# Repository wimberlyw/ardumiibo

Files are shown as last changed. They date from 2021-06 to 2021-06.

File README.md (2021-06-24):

# Arduboy Pro Rumble - With Ardumiibo Scanner
### The Arduboy Pro Rumble itself is a homemade Leonardo backpack that has a vibration motor attached to Speaker Pin 2. Game makers can use the Arduboy2 Tones commands to add rumble to their game. The system also features broken out Serial connection to connect the the Ardumiibo Scanner and future peripherals.

### The Ardumiibo scanner is a PN532 NFC Scanner with a Neopixel ring that can scan collectible items from the real world into your game. 

## An Arduboy based nod to Tiger Electronics handhelds, Rumble Features, and [Amiibos](https://www.nintendo.com/amiibo/)

### [Watch The Youtube Playlist Before You Begin](https://youtube.com/playlist?list=PLI37KAai0mUhJ3Yi7gZaNxqZhPj6SuK46)

Cover
# TOC

1. [Bill of Materials](https://github.com/wimberlyw/ardumiibo#materials-needed)
2. [Assembly](https://github.com/wimberlyw/ardumiibo#assembly)
    - Arduboy Pro Rumble Game Console
    - Powerboost
    - Boost Cables
    - Scanner
3. [Software](https://github.com/wimberlyw/ardumiibo#software)
4. [Examples](https://github.com/wimberlyw/ardumiibo#load-your-scanner-pro-micro-up-with-the-nfc-reader)  

## Materials Needed:

### Arduboy Pro Rumble:
- Arduino Leonardo
- 10mm x 2.5mm Disc Shape Vibration Motor for Cell Phone - 3v
  - Mine was from uxcel but these look just as good. (https://www.amazon.com/tatoko-12000RPM-Wired-Phone-Vibration/dp/B07L5V5GYG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)
 - 2n2222 NPN transistor
 - 3x 110 ohm resistors
 - 10uF 50V capacitor
 - Diode
 - 7x tactile momentary push buttons
 - RGB LED
 - piezo buzzer
 - On off switch
 - 2.42" i2c SSD1309 OLED
 - USB data cable (for booster cable)
 - [3d printer files](https://github.com/wimberlyw/ardumiibo/tree/main/3d%20parts)
 - [Adafruit Powerboost 500](https://www.adafruit.com/product/1944)
    - [Booster cable for Powerboost](https://learn.adafruit.com/booster-cable)
- [3.7V 1200mAh Lipo Battery](https://www.amazon.com/gp/product/B00J2QET64/ref=ppx_yo_dt_b_search_asin_title?ie=UTF8&psc=1)

### Ardumiibo Scanner
-  [3d printer files](https://github.com/wimberlyw/ardumiibo/tree/main/3d%20parts)
-  [24LED Neopixel ring] (https://www.amazon.com/gp/product/B0774JNSCF/ref=ppx_yo_dt_b_search_asin_title?ie=UTF8&psc=1)
-  [PN532 NFC Reader](https://www.amazon.com/gp/product/B01I1J17LC/ref=ppx_yo_dt_b_search_asin_title?ie=UTF8&psc=1)
- USB data cable (for booster cable)
- [Adafruit Powerboost 500](https://www.adafruit.com/product/1944)
- On off switch
- [Booster cable for Powerboost](https://learn.adafruit.com/booster-cable)
- [3.7v 500 mAh Lipo battery](https://www.amazon.com/gp/product/B00L0W61VO/ref=ppx_yo_dt_b_search_asin_title?ie=UTF8&psc=1)
- Leonardo Pro Micro
- Perfboard to mount up everything nice 
- NFC stickers for ardumiibos. (https://www.amazon.com/THONSEN-NTAG215-Stickers-Perfectly-NFC-Enabled/dp/B07MKWHYQK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)
- 

## Assembly
  	- Good luck.
  - Add hot glue as wire stress relief as you go. 
  
- Start printing the 3d printer files listed in the 3d parts section of this Github or listed in the BOM above. 

### Arduboy Pro Rumble
- You can either contact me for a pcb and I can order some more, you can make your own using the schematics from the giuthub, or you can breadboard this out. Up to you. 

### Front side PCB
1. Solder the Male header pins into the middle of the PCB so that it's like a backpack for the Leonardo. The Male pins on the PCB face **DOWN** towards the Leonardo female pins. 
backpack

2. Solder in your two resistors top right, and the 7x tactile buttons onto the top of the board. 
3. Solder in your Screen. All the pins should line up on the left hand side. If you're breadboarding this, refer to the schematics for how to hook up the display.
  -  The only items facing the front of the PCB are the buttons and those two resistors. And the Screen

### Back Side PCB

1. Install female header pins where the broken out ICSP header is. 
2. Directly beneath the female header pins, install the third resistor. 
3. Solder in the transistor with the flat part facing up, curved part towards the bottom. 
4. Solder in the diode with the white stripe facing the way it is on the board. Once again refer to the schematic for help, or the pictures on the pcb. 
5. Install the capacitor with negative stripe facing the right. 

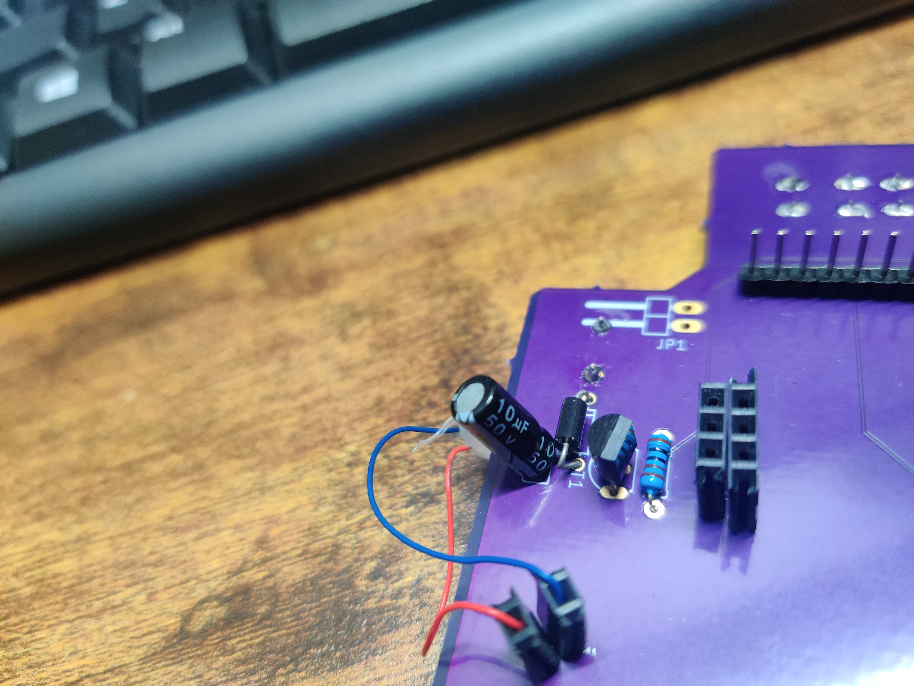
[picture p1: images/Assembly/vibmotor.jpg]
rumble


- I would install the Speaker, vibraating motor, and RGBLED on the back of the PCB. 

6. The vibrating motor goes on the two holes to the right of the capacitor circuit. Install the vibrating motor with ground wire on the left. (If PCB back is facing you.)

7. The speaker is labeled for the front, but I find it works better on the bottom of the board. the speaker wire holes are directly left of the diode.(If PCB back is facing you.) Solder in the piezo speaker with the positive wire on the left.

8. The serial cable wires are also labeled for the top, but I like them better on the bottom. You should be able to see the traces on the PCB. If the back of the OCB is facing you RX is the left hole of the gold pads. TX is the right. (the front of the board has them labeled as JP1.)

9. You're also going to need to tack a ground wire onto one of the nubs of a ground wire, as you need this for serial and I forgot. 
- This illustrates the ground wire, but the other wires are on top, which I mentioned not to do. 

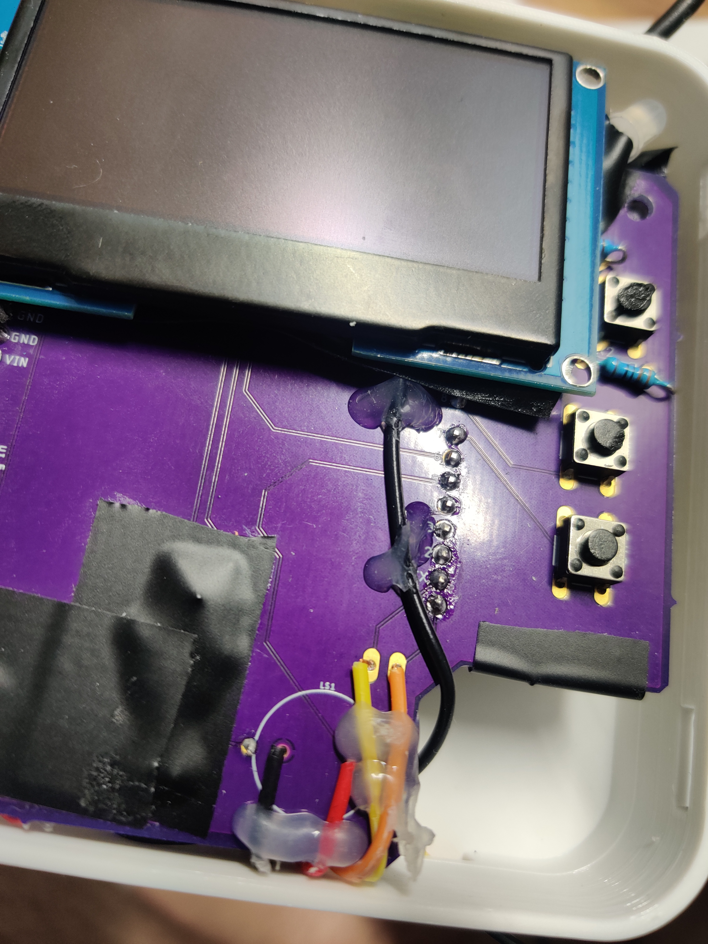
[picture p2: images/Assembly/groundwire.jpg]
Ground


##
## At this point you should be able to backpack the PCB onto the Leonardo
##
### Now we need to make the booster cables so we can power up the arduino.
  - You should probably hook everything up to your data cable at this point and run the included "Rumble Demo" to make sure everything's working right. We're about to cut up that data cable so, test it now, anyway. 
  -
  
 ## Powerboost and Booster Cables
 
 1. Follow the directions from Adafruit to hook up a switch to your Powerboost. You're going to want to mount the switch with wires instead of directly to the board so we can remote mount it. 
  - https://learn.adafruit.com/adafruit-powerboost-500-plus-charger/on-slash-off-switch

  - onOff

### You may as well wire up both powerboosts, and make two boost cables. We need the boost cables to be able to pass data through . 

2. https://learn.adafruit.com/booster-cable

## It's Time To
## Shove thaat thang in the case.
### Let me just preface this with I didn't know the powerboost would take up so much room. They look so small. 
### And I'm new to Fusion360. 
#### Sowwy. 
#### Do your best to put everything in the case and rout the USB out the top holes, and the Serial cable out the bottom. It's pretty self explanatory so here are some pictures of how I did it. Feel free to design your own case at this point. 

#### Glue down the Piezo and the vibrating motor to the back inside of the, where the empty resources are. You probably want to add a few dabs of glue to the front part of the case to keep your d pad in place, too. 

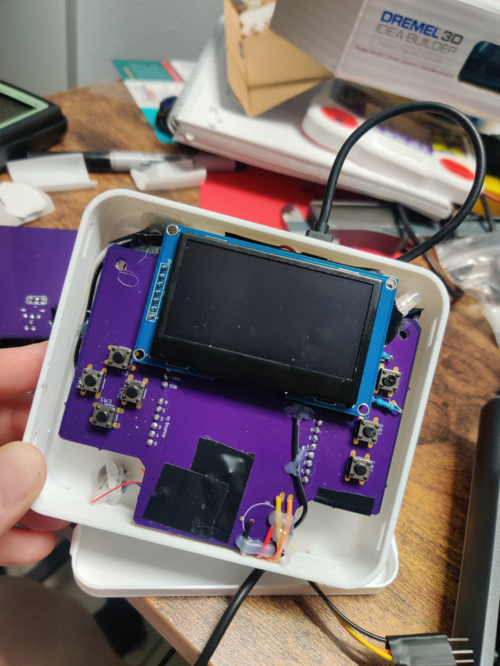
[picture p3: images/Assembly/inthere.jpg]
inthere


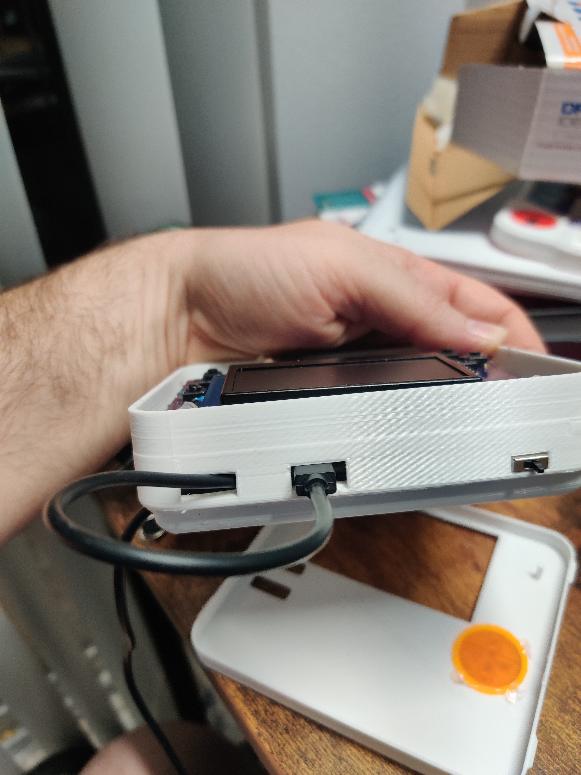
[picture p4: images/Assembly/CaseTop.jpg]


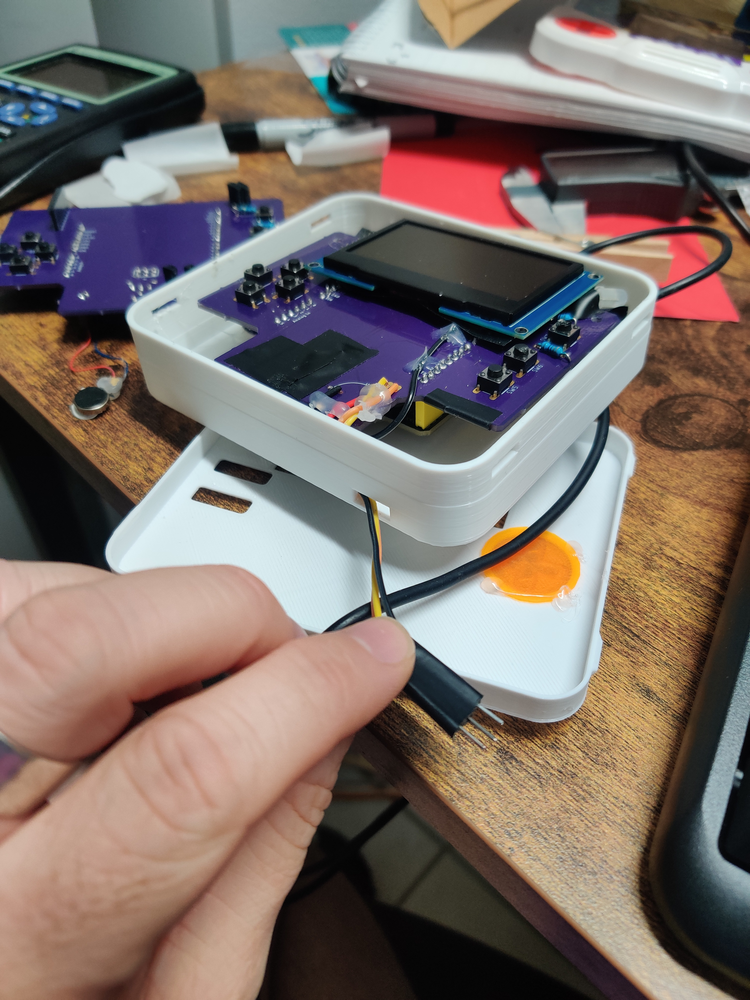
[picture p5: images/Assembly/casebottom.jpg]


## Should look like this 
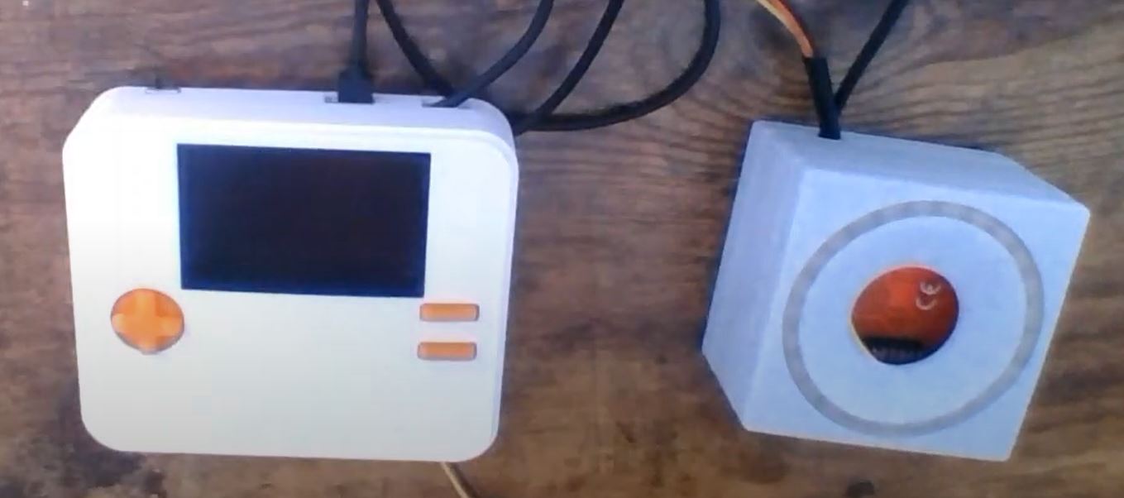
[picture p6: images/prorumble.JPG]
done


## Ardumiibo Scanner Assembly

1. On the **PN532 NFC RFID module** Solder on the 4 90 degree pins that came with your module so that they are sticking out the side that reads "TXD RXD"
2. Carefully switch the module to IIC/ I2c mode by flipping the jumper. 
  - More info can be found here: https://www.electroschematics.com/nfc-rfid-module-pn532/
  - And here: http://wiki.sunfounder.cc/index.php?title=PN532_NFC_RFID_Module
3. The Arduino Pro Micro will sit in the bottom of the Scanner case, along with the Powerboost hooked up to it's booster cable
 - https://learn.adafruit.com/booster-cable
4. The middle bdoy is where the PN532 will sit, and you will pass wires through the holes to the bottom of the case.  (If you've printed the case this will be very evident.)
5. The top faceplate is in 3 parts, and the NEOPIXEL ring is glued into the back of the light diffuser ring part. 
6. Run the wires from the top section of the box where the LEDs are, THrough the body, and into the base so you can solder them into the Pro Micro as follows. 

Pro Micro | Module
------------ | -------------
VCC | VCC PN532
VCC | 5v LED Ring 
GND | GND PN532
GND | GND LED Ring
Pin 2 | PN532/ SDA
PIN 3 | PN532/ SCL
PIN 4 | LED Ring Data In

RFIDclose

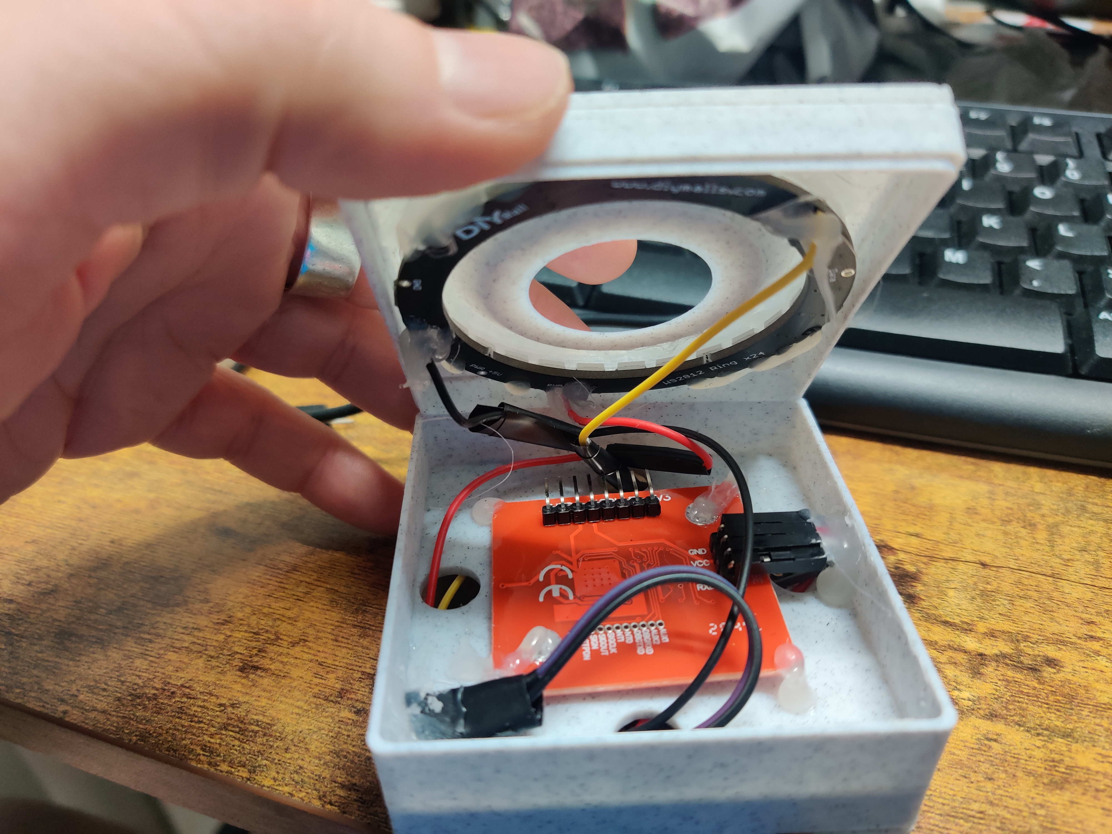
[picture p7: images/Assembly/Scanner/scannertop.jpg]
ScanTop


### Unfortunately I can't show you the wires in the pro micro because fitting everything in the box is a hard task. Once it's in there, it's in. 
 - Use plenty of hot glue for attaching and wire stress relief. 

## Software

- I use the Arduino IDE so I can't speak to the Arduboy game loaders. 
- Use Mr Blinky's homemade Package for running the 1309. Select Homemade Arduboy, Leonardo, and SSD1309. Standard Arduino Core.
  - https://github.com/MrBlinky/Arduboy-homemade-package
  - Blinky's software worked for me out of the box, but I remember way back having to change some addresses or running the patcher for uploading games. You can find out all about that on the Arduboy forums and in Mr. Blinky's docs. 

- Install the PN532 Arduino Library
  - https://github.com/Seeed-Studio/PN532/tree/arduino/PN532

- Install the Adafruit Neopixel Library 
  - https://learn.adafruit.com/adafruit-neopixel-uberguide/arduino-library-installation

### Load your scanner Pro Micro up with the NFC Reader 

- (https://github.com/wimberlyw/ardumiibo/tree/main/Scanner%20Programs)
    -  This is basically boilperplate from the PN532 libraries, and the Adafruit Neopixel library.

### Load your Arduboy Pro Rumble up with the example ScanDemo

-https://github.com/wimberlyw/ardumiibo/tree/main/Examples
 
 ### Check out the video tutorial on how to make an Ardumiibo. 
 
 - https://youtu.be/rNLjulla09I
  - Use the word "keys" for the key example
  - Use "pots" for the potion example. 
  - Try Everything out!
 
 ## Try the "Turbo Waddle" Demo!
 
 - https://youtu.be/9yPsy_AzS58
 - https://github.com/wimberlyw/ardumiibo/tree/main/Game/TurboWaddle

## Make your own game with Rumble!

- Rumble just uses the Tone library BeepPin2. 
- Essentially The scanner is just passign a string over serial. 
  -  Read the examples!

```BeepPin2 rumble; // Rumble motor runs on Speaker Pin 2

void setup() 
{rumble.begin();//Set up Rumble Motor}
  
	 if (arduboy.justPressed(B_BUTTON)) {

	rumble.tone(beep.freq(523.251), 5); /beep.freq(523.251) is used to convert 523.251Hz to the required count
	} 
```
 
## Make your own game with Ardumiibo Support!
1. Turn on :
  - ` power_usart1_enable(); // Arduboy turns off serial power, so we need that to connect to the RFID reader`
  -  `Serial1.begin(115200);// Begin communication with the Serial port/ Reader over Serial 1"` 

 2. Set up a dummy string to save the message we receive from Serial. 
`String Message;//Storing messages from the scanner as a string here. `

3. If the Serial is receiving a message, check to see if it's ours.
- If it is, do something. 

**THIS LINE MAKES SERIAL NOT LOCK UP EVERYTHING BY SCANNING ALL THE TIME, BUT ONLY WHEN DATA COMES
You could do a "Blocking" version if you wanted the user to be stuck somewhere until they scan something.  Just don't include serial available.**

`if(Serial1.available()){  
   Message = Serial1.readStringUntil('\r');     //Store incoming data `

      if(Message != ""){    
        
        //We've found that the writer apps put an extra " en/" in the string, so we take it out. 
        Message.remove(0,3);

        // if it exists, do stuff.
          if(Message.indexOf(potionCode) >= 0){      //if our code exists in what was scanned
                                    //do stuff
            Serial1.flush();   //Clear the serial buffer of any info
            arduboy.delayShort(1000);    //add a lil delay time
            heartsEarned++; 
           }

### **That's really all you need to set up your game to read from the scanner!**

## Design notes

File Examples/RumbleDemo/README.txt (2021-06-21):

\\Note, Tones don't work with the Project ABE emulator\\

The Rumble Features works off the BeepPin2 from the tones library in Arduboy2. So basically all you need to do is 
Before setup
Make an instance of BeepPin2, then call it like a normal tone. 

BeepPin2 rumble; // Rumble motor runs on Speaker Pin 2

void setup() {
 rumble.begin();//Set up Rumble Motor 
}
  
	 if (arduboy.justPressed(B_BUTTON)) {

	rumble.tone(beep.freq(523.251), 5); /beep.freq(523.251) is used to convert 523.251Hz to the required count
	}

It's that easy.

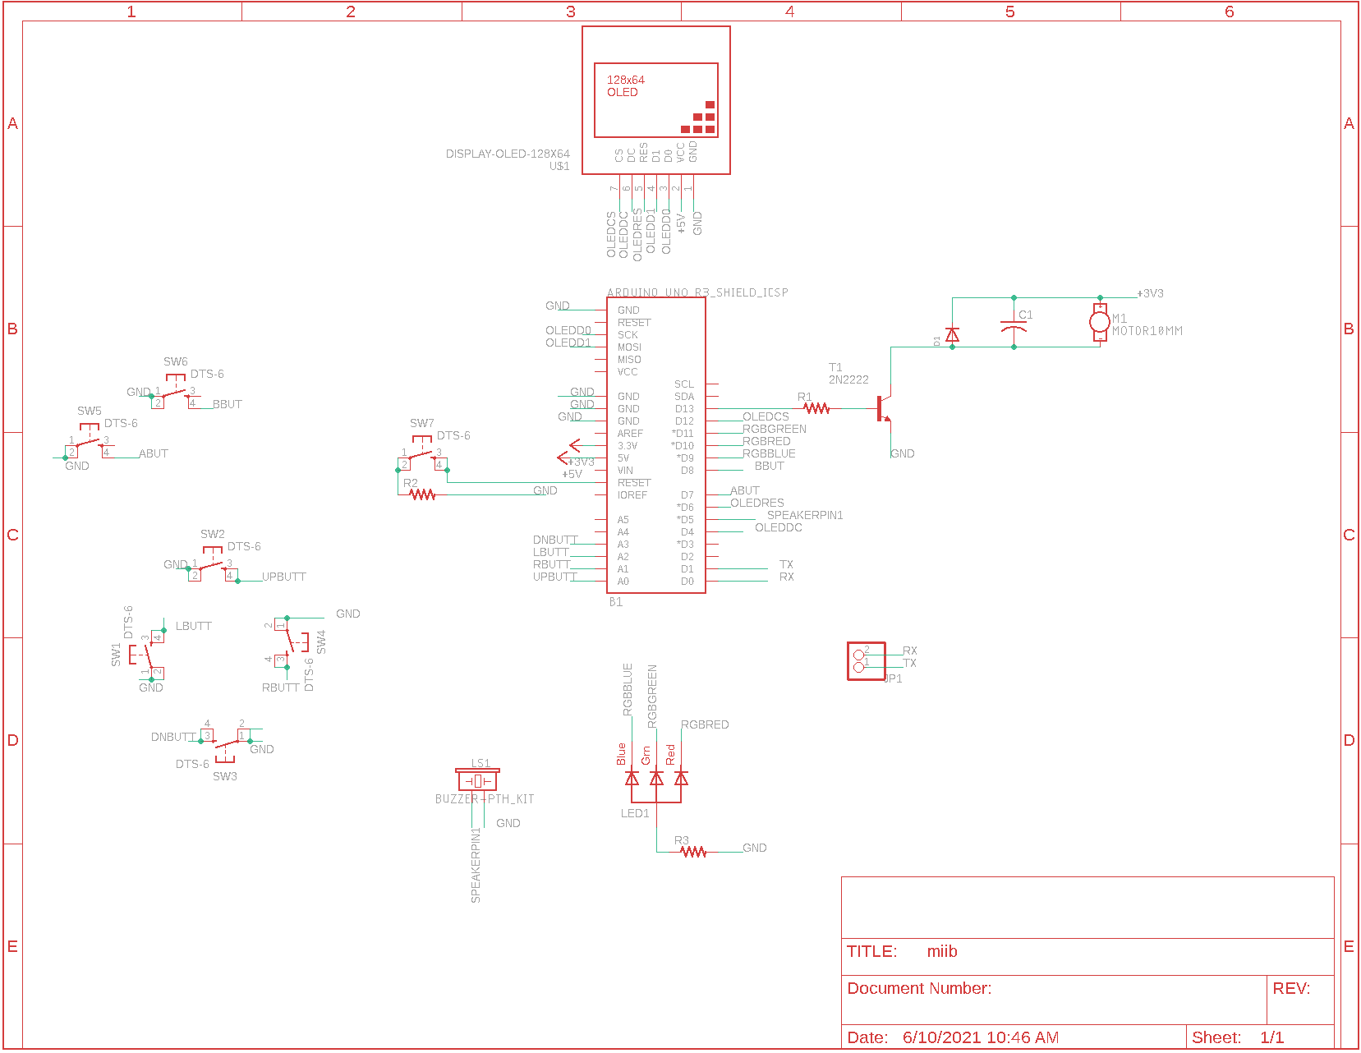
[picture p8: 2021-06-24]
Eagle Files/Arduboy Schematic/ArduboyProRumble.png

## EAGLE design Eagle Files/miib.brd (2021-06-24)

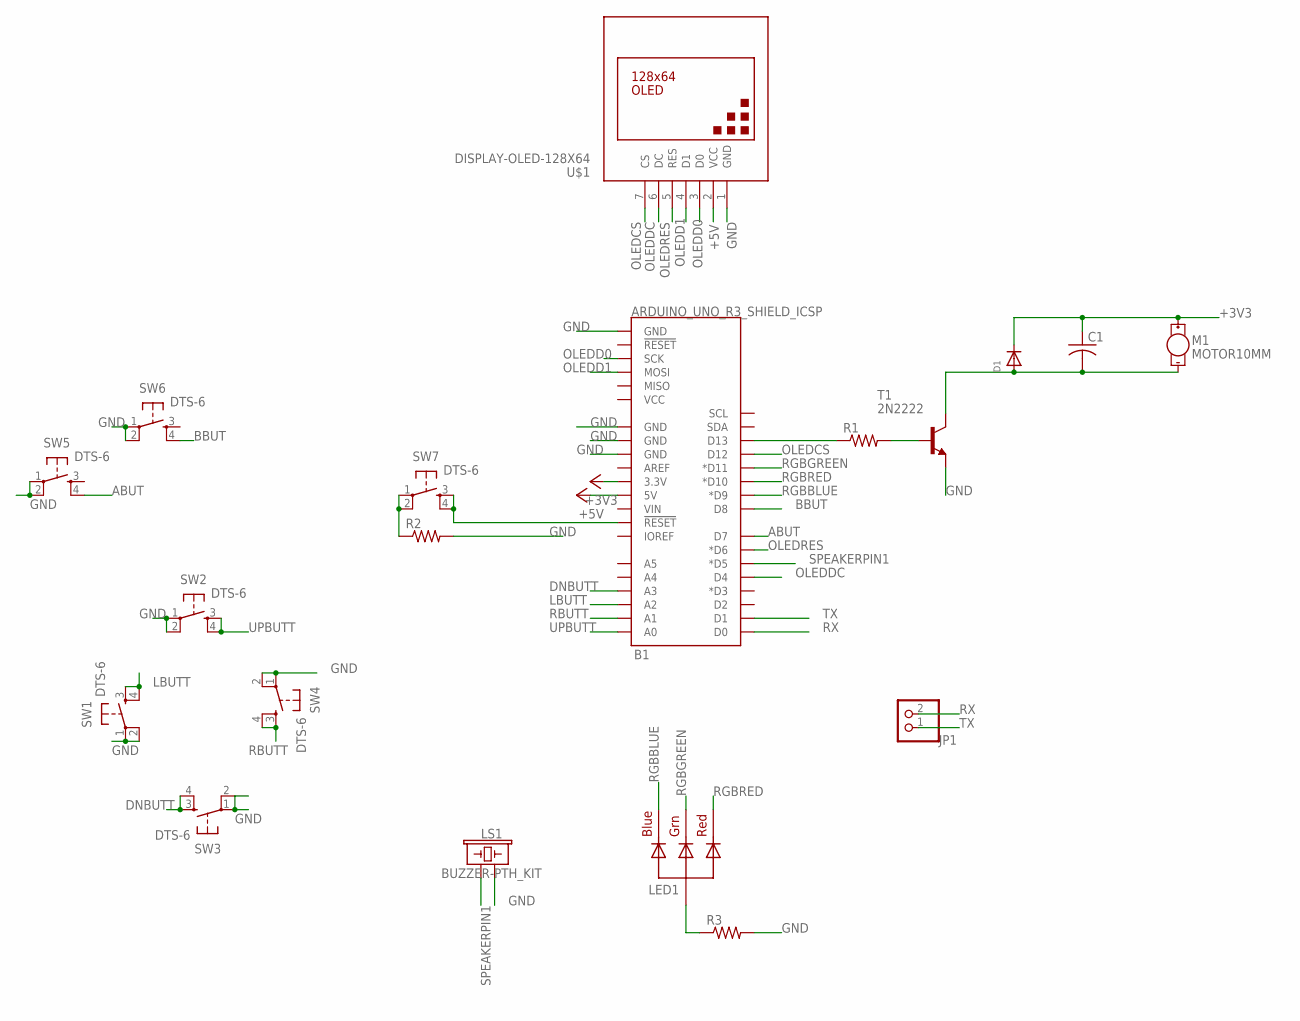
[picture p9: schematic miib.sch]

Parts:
B1: ARDUINO_UNO_R3_SHIELD_ICSP; UNO_R3_SHIELD_ICSP
C1: C-US025-025X050; C025-025X050
D1: DIODEDO-1N4148; DO-1N4148
JP1: PINHD-1X2/90; 1X02/90
LED1: RGBLED_CA-5MM; LED5MMRGB
LS1: BUZZER-PTH_KIT; BUZZER-12MM-KIT
M1: MOTOR10MM; VIBE-MOTOR-10MM
R1, R2, R3: R-US_0204/7; 0204/7
SW1, SW2, SW3, SW4, SW5, SW6, SW7: DTS-6
T1: 2N2222; TO92-EBC-OVAL
U$1: DISPLAY-OLED-128X64

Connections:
+3V3: B1.3.3V, C1.1, D1.C, M1.+
+5V: B1.5V, U$1.2 (VCC)
ABUT: B1.D7, SW5.4
BBUT: B1.D8, SW6.4
DNBUTT: B1.A3, SW3.3, SW3.4
GND: B1.GND@0 (GND), B1.GND@1 (GND), B1.GND@2 (GND), B1.GND_ICSP (GND), LS1.- (2), R2.2, R3.2, SW1.1, SW1.2, SW2.1, SW2.2, SW3.1, SW3.2, SW4.1, SW4.2, SW5.1, SW5.2, SW6.1, SW6.2, T1.E, U$1.1 (GND)
LBUTT: B1.A2, SW1.3, SW1.4
unnamed: B1.D13, R1.1
unnamed: R1.2, T1.B
unnamed: R2.1, SW7.1, SW7.2
unnamed: B1.RES (!RESET!), SW7.3, SW7.4
unnamed: C1.2, D1.A, M1.-, T1.C
unnamed: LED1.2 (VCC), R3.1
OLEDCS: B1.D12, U$1.7 (CS)
OLEDD0: B1.SCK, U$1.3 (D0)
OLEDD1: B1.MOSI, U$1.4 (D1)
OLEDDC: B1.D4, U$1.6 (DC)
OLEDRES: B1.D6 (*D6), U$1.5 (RES)
RBUTT: B1.A1, SW4.3, SW4.4
RGBBLUE: B1.D9 (*D9), LED1.4 (BLUE)
RGBGREEN: B1.D11 (*D11), LED1.3 (GREEN)
RGBRED: B1.D10 (*D10), LED1.1 (RED)
RX: B1.RX (D0), JP1.2
SPEAKERPIN1: B1.D5 (*D5), LS1.+ (1)
TX: B1.TX (D1), JP1.1
UPBUTT: B1.A0, SW2.3, SW2.4

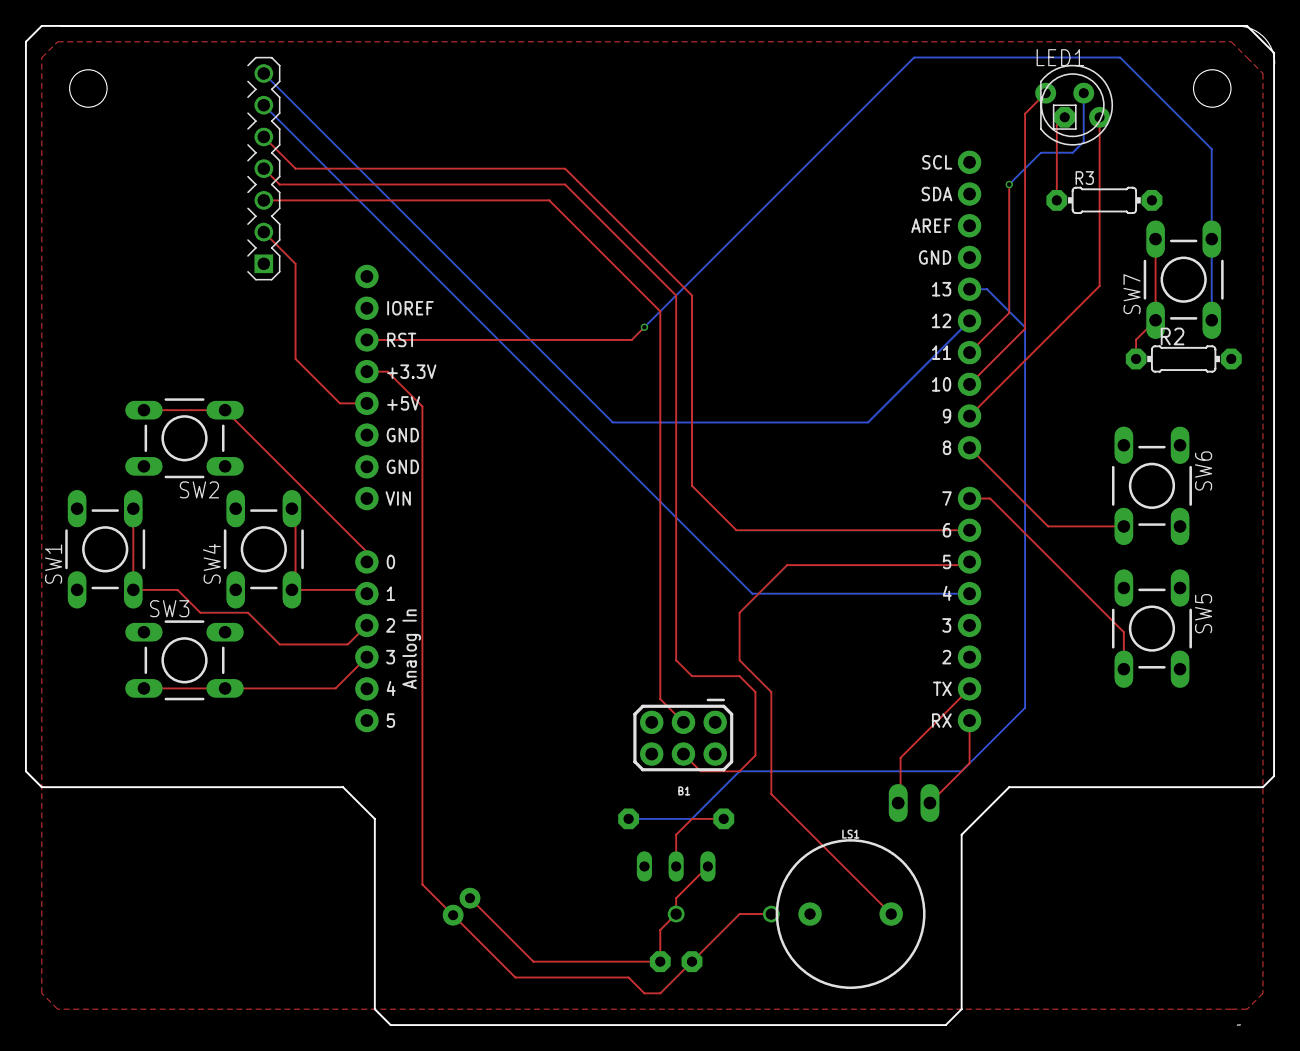
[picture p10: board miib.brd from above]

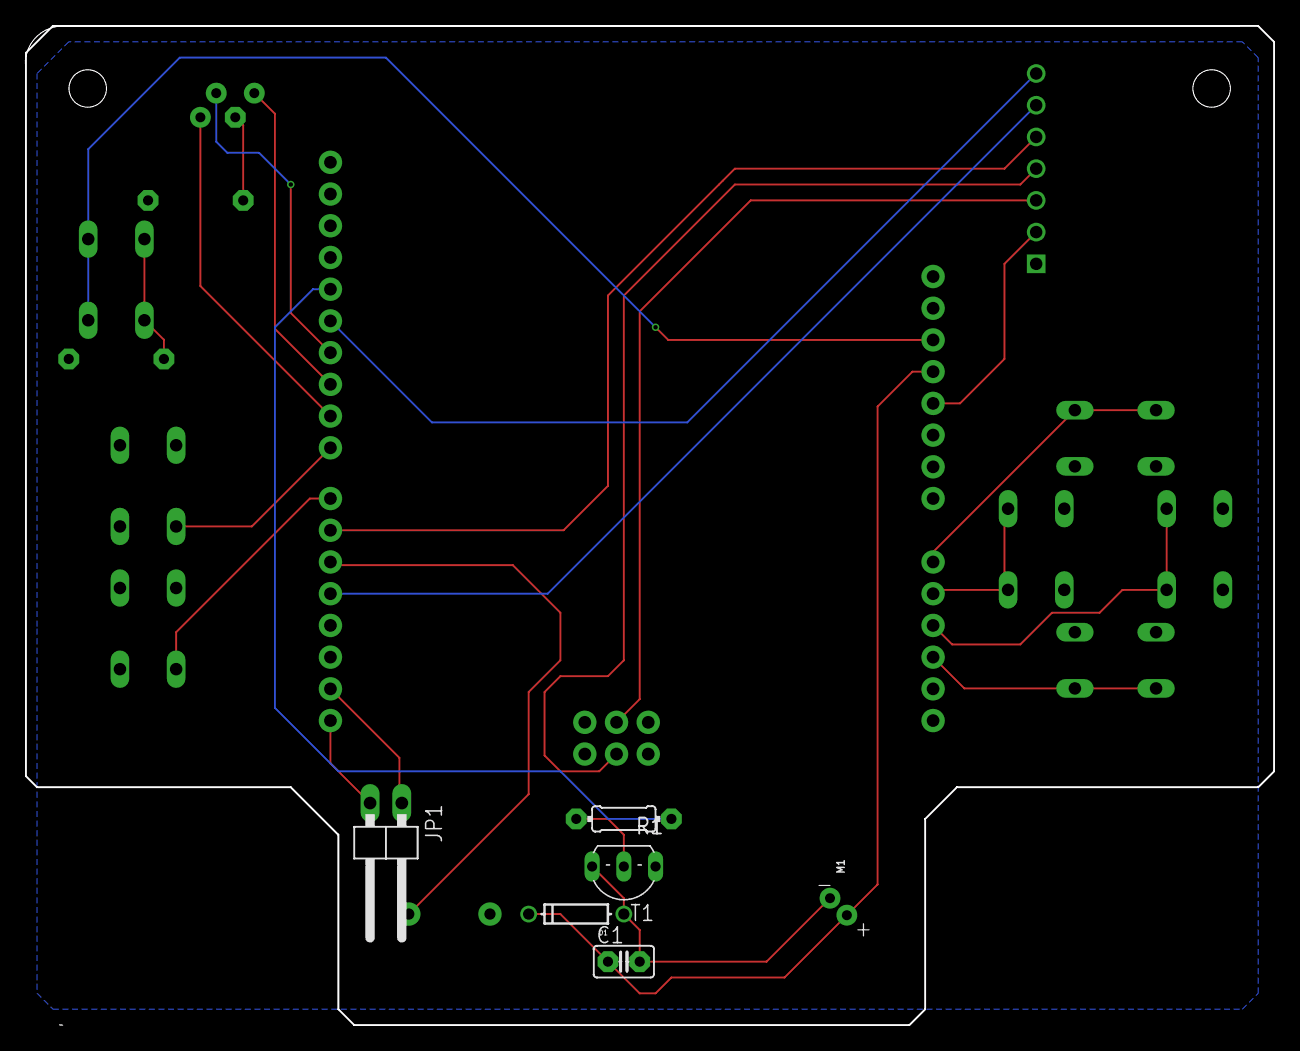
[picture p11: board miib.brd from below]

Board: 2 copper layers, 99.9 x 80.0 mm, 19 parts (6 on the bottom side), 26 nets.

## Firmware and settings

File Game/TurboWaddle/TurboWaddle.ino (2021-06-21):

//MAKE SURE TO SCAN FOR DEBUG

#include <Arduboy2.h>
//#include <ArduboyTones.h>
#include "characters.h"
#include "menus.h"

// make an instance of arduboy used for many functions
Arduboy2 arduboy;
BeepPin1 beep; // Create a class instance for speaker pin 1
BeepPin2 rumble; // For speaker pin 2, use this line instead of the line above

//ArduboyTones noise(arduboy.audio.enabled);

short spawnTimer;
short spawnDelay;
short topBarSize;
short groundBarPos;
short score;
short gameState;
short gameSpeed;
float gravity;
bool firstStep;

// CHARACTER UNLOCKS
String CharacterNames[] = {"Runner" , "Beefball", "Dino" , "C-Cube"};
bool CharacterUnlocks[] = {true     , false     , false  , false    };


struct Enemy {

  int posX, posY;
  int sizeBox;
  bool isAlive;
};



const int arSize = 8;
Enemy enemyPixel[arSize];
int backgroundLines[arSize];

PlayerOne player;
Menus gameMenu;


//####################################################
//################### START OF CODE ##################
void setup() {
  arduboy.begin();
  
  arduboy.setFrameRate(30);
  arduboy.audio.on();

//-----TURN ON SERIAL-----
  power_usart1_enable();
  Serial1.begin(115200);

//-----TURN ON RUMBLE-----
beep.begin(); // Set up the hardware for playing tones
rumble.begin();//Set up Rumble Motor

  //creates the lines and values to use for the ground or it looks weird on startup
  for (int i = 0; i < arSize; i++) {
    backgroundLines[i] = i * (arduboy.width() / arSize);
  }

  gameState = 0;
  gameSpeed = 2;
  player.animStep = 0;
  firstStep = true;

}

// ++++ game begin +++++
void loop() {
  if (!(arduboy.nextFrame()))
    return;
  beep.timer(); // handle tone duration
  rumble.timer(); //handle rumble duration
  arduboy.pollButtons();
  arduboy.clear();

  //------------------- START MENU ---------------------------------------
  if (gameState == 0) {
    // DO STUFF HERE FIRST
    if (firstStep) {
      groundBarPos = 65;
      gameMenu.ResetMenuStates();
      firstStep = false;
    }

    drawGround(groundBarPos);

    //lower intro title
    if (arduboy.everyXFrames(5)) {
      gameMenu.animStep = (gameMenu.animStep + 1) % 2;
    }

    if (groundBarPos <= 50)
    {
      short menuX = gameMenu.menuState > 0 ? -pow(gameMenu.animStepAlt - 4, 2) + 16 : 0; //fancy animation :D

      gameMenu.drawMenuTitle(32 + menuX, 0);

      // flash start selection
      if ((millis() % 1000) < 500) {
        gameMenu.Start(arduboy, 26 + menuX, 40); //flash the start button
      }
      //if not animating
      if (arduboy.everyXFrames(2) && gameMenu.menuState > 0)
      {
        gameMenu.animStepAlt++;
        if (gameMenu.animStepAlt > 15)
        { // when title is done change menu to charSelect
          gameState = 2;//the actual swap
        }
      }

      if ((arduboy.justPressed(A_BUTTON) || arduboy.justPressed(B_BUTTON)) && gameMenu.menuState == 0)
      {
        gameMenu.menuState++;
      }
    } else {
      //this allows you to skip intro animation
      if (arduboy.justPressed(A_BUTTON) || arduboy.justPressed(B_BUTTON)) {
        groundBarPos = 50;
      }

      short titlePosY = -32 * (groundBarPos - 50) / 14; //calculate top down anim
      gameMenu.drawMenuTitle(32, titlePosY);

      if (arduboy.everyXFrames(3)) {
        groundBarPos--;
      }

    }

    //end of menu
    if (gameState != 0) {
      firstStep = true;
      gameMenu.ResetMenuStates();
    }
    arduboy.display();
  }
  //------------------- CHARACTER SELECT ---------------------------------
  else if (gameState == 2) {
    if (firstStep) {
      groundBarPos = 50;
      gameMenu.ResetMenuStates();
      firstStep = false;
    }
    drawGround(groundBarPos);

    gameMenu.CharacterSelect(arduboy, CharacterNames, CharacterUnlocks, 0, 0);

    //NEEDS TO SWOOS RIGHT IN
    // FIX IT

    if (arduboy.justPressed(B_BUTTON)) {
      if ( gameMenu.select < 4) {
        if (CharacterUnlocks[gameMenu.select]) 
        {
          player.selectedChar = CharacterNames[gameMenu.select];
          gameState = 1;//Change to main game loop
        }
      } else if (gameMenu.select == 4) {
        gameState = 3;//change to Scan menu
      }

    } else if (arduboy.justPressed(A_BUTTON)) {
      gameState = 0;
    }

    //if exiting the current gameState, reset.
    if (gameState != 2) {
      firstStep = true;
    }
    arduboy.display();
  }
  //------------------- SCAN MENU ----------------------------------------
  else if (gameState == 3) {
    if (firstStep) {
      groundBarPos = 50;
      gameMenu.ResetMenuStates();
      firstStep = false;
      gameMenu.menuState = -1;
    }
    
    gameMenu.ScanMenu(arduboy, CharacterNames, CharacterUnlocks, 0, 0);
    if(gameMenu.menuState == 7){
      gameState = 2;
      firstStep = true;
    }

    arduboy.display();
  }
  //------------------- MAIN GAME ----------------------------------------
  else if (gameState == 1) {
    //--------------------------------------------------------------------
    // --------Here is where you initialize the game, not in setup--------
    if (firstStep) {
      spawnTimer = 0;
      spawnDelay = 33; // time between spawns editable (33 = 1sec)
      topBarSize = 8;
      groundBarPos = 50;
      score = 0;
      gravity = 0;
      randomSeed(millis()%9999);

      player.posY = groundBarPos - 16;
      player.posX = 24;
      player.shield = 50;
      player.canJump = false;
      //player.selectedChar = "dino";



      for (int i = 0; i < arSize; i++)
      {
        enemyPixel[i].sizeBox = 5;
        enemyPixel[i].posX = 130;
        enemyPixel[i].posY = 32;
        enemyPixel[i].isAlive = false;
      }

      firstStep = false;
    }
    //--------------------------------------------------------------------
    //--------------------------------------------------------------------

    drawGround(groundBarPos);

    // PLAYER JUMP CONTROL
    int jumpOffset = groundBarPos; //where the chracters actual ground is

    if ((arduboy.justPressed(A_BUTTON) || arduboy.justPressed(B_BUTTON)) && player.canJump) {
      gravity = 5;
      player.canJump = false;
      player.posY = jumpOffset - 1;
    }
    else if (player.posY < jumpOffset) {
      //if player is not on ground
      player.posY = player.posY - (int)gravity;
      gravity = gravity - 0.5f;

      //alternative to math.clamp()
      if (player.posY > jumpOffset) {
        player.posY = jumpOffset;
      }
    }
    else { //set player to ground and stop movement
      gravity = 0;
      player.canJump = true;
    }


// ------------- ENEMY CONTROLS ----------------

    for (int i = 0; i < arSize; i++) {

      if (enemyPixel[i].isAlive == true) { //ENEMY DRAW LOOP
        if (enemyPixel[i].posX > (0 - enemyPixel[i].sizeBox)) { // if enemy is on screen
          arduboy.fillCircle(enemyPixel[i].posX, enemyPixel[i].posY, enemyPixel[i].sizeBox, BLACK); // DRAW CALL
          arduboy.drawCircle(enemyPixel[i].posX, enemyPixel[i].posY, enemyPixel[i].sizeBox, WHITE); // DRAW CALL

          enemyPixel[i].posX = enemyPixel[i].posX - gameSpeed;//DRAW CALL

          int distX = enemyPixel[i].posX - player.posX;
          int distY = enemyPixel[i].posY - player.posY;


// ------ COLLISION / DAMAGE CHECK ------
          if ( (abs(distX) < (enemyPixel[i].sizeBox * 2) ) && ( abs(distY) < (enemyPixel[i].sizeBox * 2) ))
          {
            enemyPixel[i].isAlive = false;            
            player.shield = player.shield - 10;

            //-------- DAMAGE EFFECTS GO HERE --------- //they will happen ONCE when you get hit.

            beep.tone(beep.freq(523.251), 10);
            rumble.tone(beep.freq(523.251), 10);
            //--------------------------------------------  
            
            //go to another state if your health is 0
            beep.tone(beep.freq(523.251), 10);
            rumble.tone(beep.freq(523.251), 10);
            arduboy.invert(true);
            delay(75);
            arduboy.invert(false);
          }
        } else {
          enemyPixel[i].isAlive = false; //kill enemy if its off screen
        }
      } else {
        if (spawnTimer >= spawnDelay) {
          //enemyPixel[i].size = 4;
          enemyPixel[i].posX = 128 + enemyPixel[i].sizeBox * 2;
          enemyPixel[i].posY = (groundBarPos - enemyPixel[i].sizeBox * 2 + 12); // REMOVE THE 50
          enemyPixel[i].isAlive = true;

          if (score > 2000) {
            gameSpeed = 6;
            spawnDelay = 25 - random(0, 8);
            enemyPixel[i].posY = enemyPixel[i].posY - (random(0, 2) == 0 ? 20 : 0);
          } else if (score > 1500) {
            gameSpeed = 5;
            spawnDelay = 33 - random(0, 13);
            enemyPixel[i].posY = enemyPixel[i].posY - (random(0, 2) == 0 ? 20 : 0);

          } else if (score > 1000) {
            gameSpeed = 4;
            spawnDelay = 33 - random(0, 10);
            enemyPixel[i].posY = enemyPixel[i].posY - (random(0, 3) == 0 ? 20 : 0);

          } else if (score > 750) {
            spawnDelay = 44 - random(0, 15);
            enemyPixel[i].posY = enemyPixel[i].posY - (random(0, 3) == 0 ? 20 : 0);

          } else if (score > 500) {
            gameSpeed = 3;
            spawnDelay = 55 - random(0, 20);
            enemyPixel[i].posY = enemyPixel[i].posY - (random(0, 4) == 0 ? 20 : 0);

          } else if (score > 0) {
            gameSpeed = 2;
            spawnDelay = 66 - random(0, 33);
          }

          spawnTimer = 0;

        }
      }
    }


    score = score + 1;

// DRAW CALLS
    displayAll();
    arduboy.display();

    if (player.shield <= 0) {
      screenFlash(4, 250);
      gameState = 0;
      gameSpeed = 2;
      firstStep = true;
    }

    if (spawnTimer < spawnDelay) {
      spawnTimer++;
    } //SPAWN COUNTER
  }

}
// END OF GAME

//#######################################################################################
//#################################### FUNCTIONS ########################################
void displayAll() {
  drawShieldBar(1, topBarSize - 7, player.shield);
  drawTopBar(topBarSize);
  //drawGround(groundBarPos);
  drawScore(77, topBarSize - 8, score);
  drawPlayer(player.posY, player.posX);
}

void drawTopBar (int posY) {

  arduboy.drawFastHLine(0, posY, 128, WHITE);

} // Draws the top score bar

void drawGround (int posY) {

  //arduboy.drawFastHLine(0, posY, 128, WHITE);

  int botY = arduboy.height();
  for (int i = 0; i < arSize; i++) {

    //dots inbetween. Same positions as the lines, but shifted by half the amount
    arduboy.drawPixel(backgroundLines[i] + ((arduboy.width() / arSize) / 2), posY);

    backgroundLines[i] -= gameSpeed / 2;
    if (backgroundLines[i] < 0) {
      backgroundLines[i] = arduboy.width();
    }


    int topPos = backgroundLines[i] + (2 * backgroundLines[i] - arduboy.width());
    arduboy.drawLine(backgroundLines[i], posY, topPos, botY);
  }
}

//Draws a triagle represented by the player
void drawPlayer(int yPos, int xPos) {

  if (player.canJump) {
    int frameskip = 5 - gameSpeed;
    if (frameskip < 1) {
      frameskip = 1;
    }
    if (arduboy.everyXFrames(frameskip)) {
      player.animStep = (player.animStep + 1) % 4;
    }
  } else {
    player.animStep = 4;
  }

  // -8 for the offset of the 16x16 sprite
  Sprites::drawSelfMasked(xPos - 8, yPos - 8, player.getSpriteSet(player.selectedChar), player.animStep);
}

void drawShieldBar(int posX, int posY, int shield) {
  int spacing = 4;
  int width = 50;

  int originX = posX + width + spacing * 2 - 2;
  int originY = posY + 2;
  int scale = 1;

  //BAR
  arduboy.drawRoundRect(posX, posY, width, 5, 2, WHITE);
  if (shield > 20 ) {
    arduboy.fillRoundRect(posX, posY, shield, 5, 2, WHITE);
  }
  else if (shield > 10) {
    if ((millis() % 500) > 250) {
      arduboy.fillRoundRect(posX, posY, shield, 5, 2, WHITE);
    }
  }
  else if (shield > 0) {
    if ((millis() % 250) > 125) {
      arduboy.fillRoundRect(posX, posY, shield, 5, 2, WHITE);
    }
  }

  //SYMBOL
  arduboy.drawChar(posX + width + spacing * 0, posY - 1, '(', WHITE, BLACK, 1);
  arduboy.drawChar(posX + width + spacing * 2, posY - 1, ')', WHITE, BLACK, 1);

  int tip1x = originX + (3 * scale);
  int tip1y = originY;

  int tip2x = originX - (2 * scale);
  int tip2y = originY + (2 * scale);

  int tip3x = originX - (2 * scale);
  int tip3y = originY - (2 * scale);
  arduboy.drawTriangle(tip1x, tip1y, tip2x, tip2y, tip3x, tip3y, WHITE);
} // Draws the shield bar for health

void drawScore(int posX, int posY, int score) {

  arduboy.setCursor(posX, posY);
  arduboy.print("sc:" + String(score));

} // draw and handle score

void screenFlash(int flashAmount, short flashTime) {
  int t = flashAmount * 2 + 1;
  for (int i = 0; i < t; i++) {
    arduboy.invert(i % 2);
    delay(flashTime);
  }
}

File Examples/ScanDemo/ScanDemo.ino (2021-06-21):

#include <Arduboy2.h>
#include "sprites.h"

// make an instance of arduboy used for many functions
Arduboy2 arduboy;

//   ---------------------- Menu positions and such
byte UIX = WIDTH - 36;
bool scanON;
int heartsEarned =2;
int heartsMax = 3;
int characterX = 32;
int characterY = HEIGHT - 32;
bool facingLeft = true;
bool hasKey = false;
int spriteFrame = 0;

//-------------------------------RFID Scanner Variables
String Message;//Storing messages from the scanner as a string here. 

// ------------Set your secret code you want to read from the RFID.
// The  "codes" we will be scanning for. 
// i.e a character name or whatever you want to write to your rfid tags to read here.  
// All the writers write with the word "en" in front 
// so you have to include en in front, 
// Or skip the first 3 chars if comparing the string. 
// This example skips the first 3 chars

String keyCode = "keys"; 
String  potionCode = "pots";

 
// first character is an initialize, you just can't see it. 
// Some other weird stuff we found was that if you're comparing strings, 
// Serial1.readString will add an invisible \r to the end of the string, 
// so watch that if you compare the string directly. 

//   ---------------  This code is activated when you try to read the door. So if you DONT want to just scan whenever, but on a certain event instead, do this. 
void scanFromMenu(){
  if(!scanON){arduboy.display();}

  else{
 // -------------------------------------------Blocking Scan Loop-------------------
 //This loop is blocking so we only start it when scanON is true. 
 
     arduboy.setCursor(4,9);
     arduboy.print("Scan a key to enter");
     arduboy.display();
     //read 
      //if(Serial1.available())  //WE COMMENT OUT THIS LINE HERE SO IT WILL BLOCK THINGS UNTIL YOU SCAN WHAT IT WANTS. We uncomment it in the scan anytime function. 
     {Message = Serial1.readString();} //Store String received in Message

     //
     //Check to see if your secret code (in this case the code for the Key) is contasined in the Message we received from Serial1
     //
     //
     if(Message.indexOf(keyCode) >= 0){   //Search the message for our code, set in setup
         arduboy.clear();
         //----------------This is where your reaction to scanning a match goes. 
         //Mine sets a global variable to display a key, 
         // and also Brings up a big painted rectangle that confirms you've scanned the right stuff. 
         //currentlty this will block until you DO scan the right stuff.
         //
         hasKey= true; 
         arduboy.fillRect(0,0,WIDTH, HEIGHT, WHITE);
         arduboy.fillRect(4,4,WIDTH-8, HEIGHT-8, BLACK);
         arduboy.setCursor((WIDTH/2)-30, (HEIGHT/2)-7);
         arduboy.print("Key Scanned!");
         arduboy.display();
         arduboy.delayShort(2500);
         scanON = false;  //this just pops me out of my loop and back to the menu next go around. 
         
          //Serial1.end();  //   You could end the serial connection and disable the power to serial if you wanted to after one scan. You could probably turn it back on...not sure
          //power_usart1_disable();
       
      
     } 
     //Could cancel a scan if you spam it
       if (arduboy.pressed(B_BUTTON)) {
        scanON = false;
        
      }
  }
}

// ----------------------For Scanning anytime  NONBLOCKING ----------------------
void scanAnytime(){
   if(Serial1.available()){  //THIS LINE MAKES SERIAL NOT LOCK UP EVERYTHING BY SCANNING ALL THE TIME, BUT ONLY WHEN DATA COMES
   Message = Serial1.readStringUntil('\r');     //Store incoming data
   
   if(Message != ""){    
        
        //We've found that the writer apps put an extra " en/" in the string, so we take it out. 
        Message.remove(0,3);
                
                          
        // if it exists, do stuff.
          if(Message.indexOf(potionCode) >= 0){      //if our code exists in what was scanned
                                    //do stuff
            Serial1.flush();   //Clear the serial buffer of any info
            arduboy.delayShort(1000);    //add a lil delay time
            heartsEarned++; 
           }

           if(Message.indexOf(keyCode) >=0){
            Serial1.flush();   
            arduboy.delayShort(1000);
            hasKey =true;
            
           }
        }   
    }
}

void playerInput(){
  arduboy.pollButtons();
  if (arduboy.pressed(LEFT_BUTTON) && characterX>0) {characterX-=1, spriteFrame++; facingLeft = true;}
  if (arduboy.pressed(RIGHT_BUTTON) && characterX + 32< WIDTH-16) {characterX+=1,spriteFrame++; facingLeft=false;}
  if (arduboy.justPressed(B_BUTTON) && heartsEarned>=0) {heartsEarned--;} 

  if(arduboy.justPressed(A_BUTTON) && characterX == WIDTH-48){
    arduboy.clear();
    scanON = true; // ------------Enter the loop to Scan things;}
    
  }
  
}

void drawui(){
  // -------------------Draw the Hearts
  arduboy.fillRect(UIX, 0, 48, 8, BLACK);
  arduboy.setCursor(UIX, 0);
  arduboy.print("[");
  arduboy.setCursor(UIX+30,0);
  arduboy.print("]");
  (heartsEarned>heartsMax)&&(heartsEarned=heartsMax);
  for( int k =0; k<heartsEarned; k++ ){Sprites::drawOverwrite((k*9)+UIX+5, 0, heart, 0);}
  //-------------------Draw the Key
  arduboy.fillRect(UIX, 10, 48, 8, BLACK);
  arduboy.setCursor(UIX, 10);
  arduboy.print("[");
  if(hasKey){Sprites::drawOverwrite(9+UIX+5, 10, key, 1);}
  else{Sprites::drawOverwrite(9+UIX+5, 10, key, 0);}
  arduboy.setCursor(UIX+30,10);
  arduboy.print("]");
  Sprites::drawOverwrite(UIX + 16, HEIGHT -16, doa, 0);
  scanFromMenu();

}
void drawCharacter(){
  if(spriteFrame>5){spriteFrame=0;}
  if(facingLeft){Sprites::drawOverwrite(characterX, characterY, GL0, spriteFrame);}
  else{Sprites::drawOverwrite(characterX, characterY, GR0, spriteFrame);}
  
}


void setup() {
  // initiate arduboy instance

  // here we set the framerate to 30, we do not need to run at
  // default 60 and it saves us battery life
  arduboy.begin();
  arduboy.setFrameRate(30);


 
 scanON = false; //dont start in scanning mode until you enter the scan option on the menu
 arduboy.audio.off();

 power_usart1_enable(); // Arduboy turns off serial power, so we need that to connect to the RFID reader
 Serial1.begin(115200);// Begin communication with the Serial port/ Reader over Serial 1
        
}


// our main game loop, this runs once every cycle/frame.
// this is where our game logic goes.
void loop() {
  // pause render until it's time for the next frame
  if (!(arduboy.nextFrame()))
    return;

  playerInput();
  arduboy.clear();
  drawCharacter();
  drawui();
  scanAnytime();
 
}

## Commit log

2021-06-21 do
    yes
    [BottomArduiiboCase.stl, InnerConeArduiiboCase.stl, LightdifArduiiboCase.stl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]
2021-06-24 Remove duplicate files
    [BottomArduiiboCase.stl, InnerConeArduiiboCase.stl, LightdifArduiiboCase.stl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]
2021-06-24 Updated BOM
2021-06-24 Eagle Files Added
    [miib.brd, miib.sch]

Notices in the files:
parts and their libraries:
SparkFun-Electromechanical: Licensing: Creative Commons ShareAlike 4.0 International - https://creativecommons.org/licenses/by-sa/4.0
